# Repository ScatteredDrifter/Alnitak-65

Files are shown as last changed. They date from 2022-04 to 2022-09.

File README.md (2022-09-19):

# Alnitak-65

typical plain-c with the twist of supporting Alps and a weird 8u, flipped Iso-Enter layout

The outlines and mounting hole positions were taken from the [bakeneko60](https://github.com/kkatano/bakeneko-65)

---

### Current Status:

- Prototypes arrived; fully tested and working 

- tray mount / bakeneko65 case compatible 

---

## Alnitak-65:

the largest keyboard among my three-board-series named after the three bright stars forming the omnipresent orion belt you can perceive within the night.

Its the typical 65% keyboard with a blocker and separated arrow-keys within the bottom-row but it supports ALPS-Switches. Thats they biggest point to distinguished the board from other designs.

If you wish to order your own pcb and case, you can find all the necessary files within this repository 

---

## Features:

- one layout option:

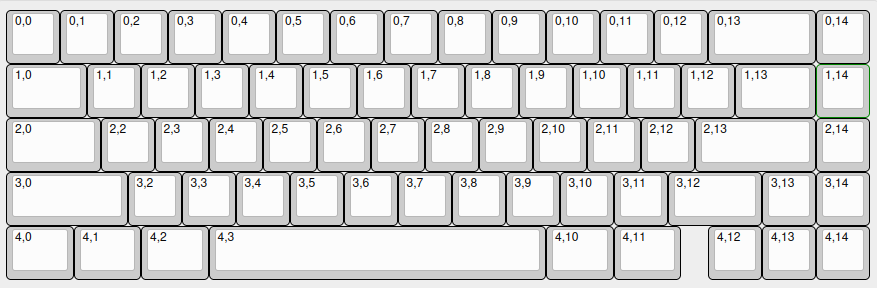
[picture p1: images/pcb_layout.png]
Available Layout


- pcb-outlines support the use of a bakeneko65 case

- jst-connector implemented, supporting the use of the unified daughterboard **C3** 

- mounting holes for typical tray-mount cases **not tested yet**

- Supports both alps and mx-style switches 

---

## Images:

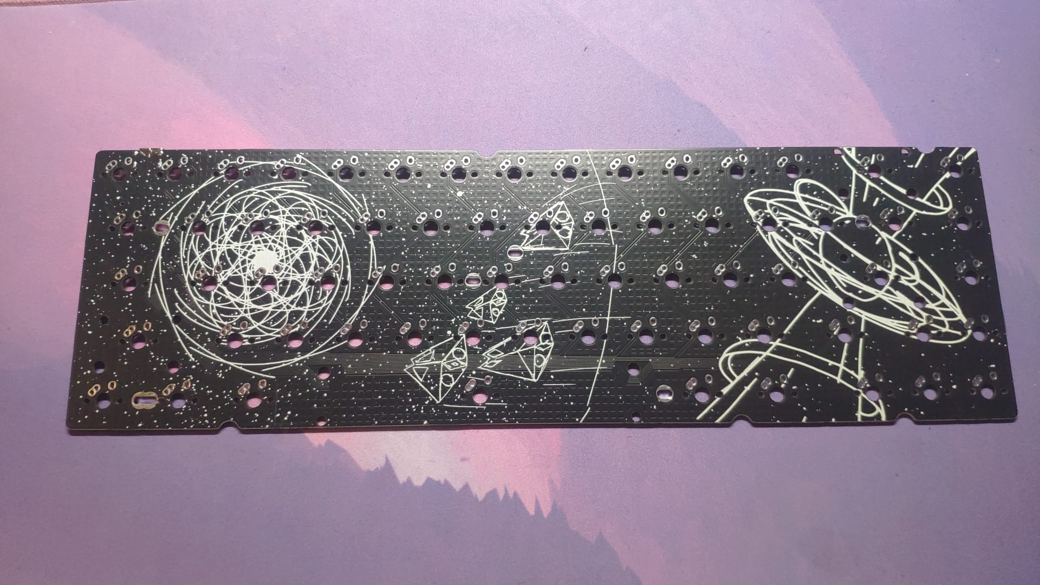
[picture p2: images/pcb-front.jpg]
Image of prototype pcb - front


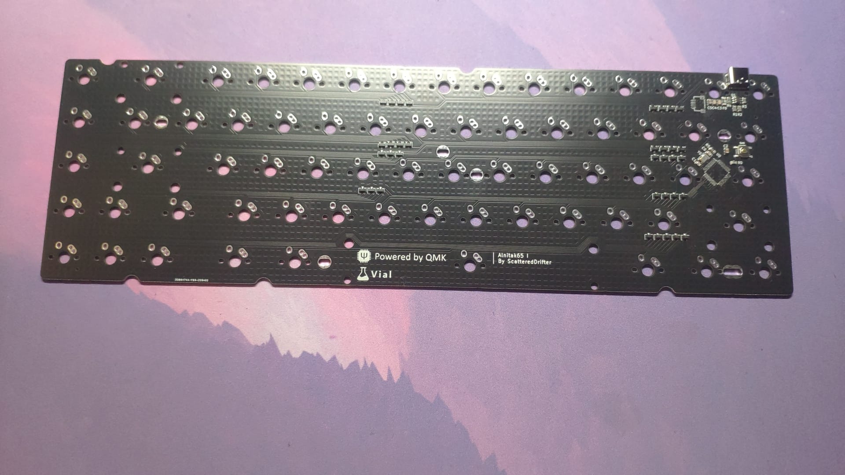
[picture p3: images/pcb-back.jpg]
Image of prototype pcb - back


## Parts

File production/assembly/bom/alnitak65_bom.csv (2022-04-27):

Comment | Designator | Footprint | LCSC
22pf | C0,C1 | Capacitor_SMD:C_0805_2012Metric | C1804
1uf | C2 | Capacitor_SMD:C_0805_2012Metric | C28323
.1uf / 100nf | C3,C4 | Capacitor_SMD:C_0805_2012Metric | C49678
10uf | C5 | Capacitor_SMD:C_0805_2012Metric | C91245
BAV70_Small | D1,D14,D114,D203,D405,D414,D607,D809,D1011,D1213,D1415,D1617,D1819,D2021,D2324,D2526,D2728,D3031,D3334,D3536,D3738,D4041,D4344,D10011,D12013,D29210,D39310,D110111,D112113,D211212,D213214,D311312,D313314,D410411,D412413 | Package_TO_SOT_SMD:SOT-23 | C68978
Polyfuse | F0 | Fuse:Fuse_1206_3216Metric | C69688
USB_C_Receptacle_USB2.0 | J0 | Connector_USB:USB_C_Receptacle_HRO_TYPE-C-31-M-12 | C165948
KEYSW | K0,0,K0,1,K0,2,K0,3,K0,4,K0,5,K0,6,K0,7,K0,8,K0,9,K0,10,K1,0,K0,11,K1,1,K0,12,K1,2,K0,13,K1,3,K0,14,K1,4,K1,5,K1,6,K1,7,K1,8,K1,9,K2,0,K2,2,K2,3,K2,4,K2,5,K2,6,K2,7,K2,8,K2,9,K3,0,K3,2,K3,3,K3,4,K3,5,K3,6,K3,7,K3,8,K3,9,K4,0,K4,2,K4,3,K4,4,K1,10,K1,11,K1,12,K1,13,K1,14,K2,10,K2,11,K2,12,K2,13,K2,14,K3,10,K3,11,K3,12,K3,13,K3,14,K4,10,K4,11,K4,12,K4,13,K4,14 | kbd:keyswitch_cherrymx_alps_combo_fixed
10k | R0,R5 | Resistor_SMD:R_0805_2012Metric | C17414
22 | R1,R2 | Resistor_SMD:R_0805_2012Metric | C17561
5.1k | R3,R4 | Resistor_SMD:R_0805_2012Metric | C27834
SW_PUSH | SW0 | Keebio-Parts:SW_SPST_TL3342 | C318884
ATmega32U2-A | U0 | Package_QFP:TQFP-32_7x7mm_P0.8mm | C618733
SRV05-4 | U1 | Package_TO_SOT_SMD:SOT-23-6 | C85364
Crystal_GND24_Small | Y0 | Crystal:Crystal_SMD_3225-4Pin_3.2x2.5mm | C13738
JST ai30 daughterboard | j1 | kbd:Aio3_jst | C2845363

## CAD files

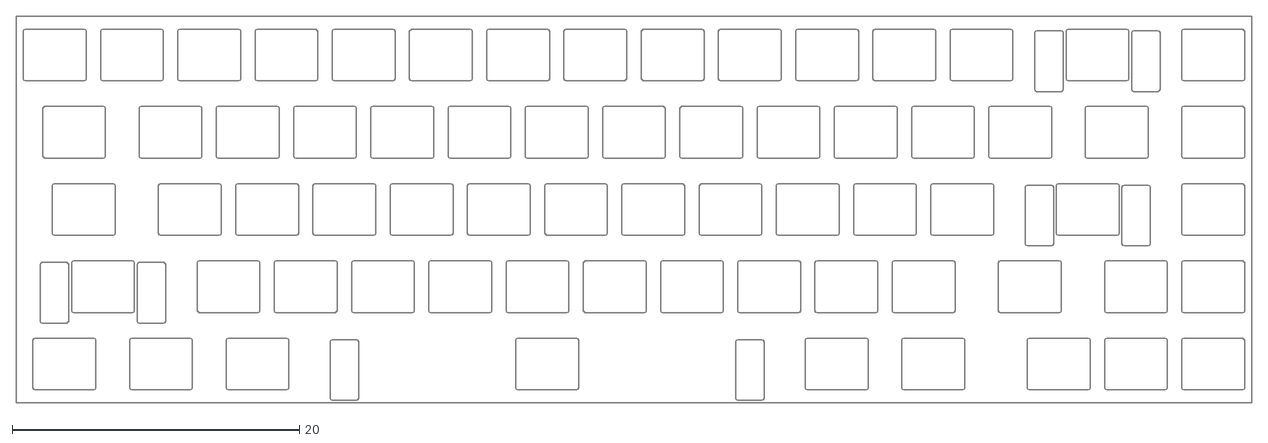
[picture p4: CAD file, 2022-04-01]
plate/plate.dxf
86.0 x 26.9

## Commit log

2022-04-01 initialized files, first commit
    [alnitak65_bom.csv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]
2022-04-01 finalized gerber and production files
    [pcb-bottom-pos.csv]
2022-04-01 fixed gerber and updated prod files
    [pcb-B_Cu.gbr, pcb-B_Fab.gbr, pcb-B_Mask.gbr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]
2022-04-27 updated bom, plate
    [alnitak65_bom.csv, pcb.kicad_sch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]
